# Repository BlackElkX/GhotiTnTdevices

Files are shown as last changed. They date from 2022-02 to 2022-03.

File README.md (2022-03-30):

# GhotiTnTdevices

Self build esp device to transform simple LED-strip designligts into wifi controlled dimable devices.

A very simple ui is available in browser.
A rest api is available.

- A schema and pcb layout is available, in the directory fritzing
- I use IR540 mosfets to drive the led strips. They stay very cool, because they are overrated for these strips.
- As source, the original 24V power suply is powerfull enough.
- I use as development and debug a NodeMCU ESP8266 module.
- As production boards, D1 mini is used.
- For the button array, I use 4x 10k ohm resistors, whish give on the NodeMCU
   - values 10, 550, 730, 815
   - a hysteresis of 42
   - and maxvalue of 980

  I did some tests, with other resistors, but 10k is the most stable.
   (dataExample/config.json is based on this tests)

  On D1 mini its more accurate, hyst is lower and values are different.

  To calibrate, use serial console, uncomment Serial.println line in main::readAnalogSensor(...
  - Serial.println("old = " + String(oldValue) + " new = " + String(newValue) + " max = " + String(maxValue) + " min = " + String(minValue));

Even Tasmota mentioned this board only suport up to 5 PWM channels, driving 6 PWM channels is not a problem.

V 0.0.7 - More scenes.
-------------------------------------

Todo:
- a switch to disable wifi functionality (only when power is off, you can use it. If powered, the switch will not be checked)
- a power switch (only on hardware level)
- an ap wifi mode with fixed ip address
- saving the config into the config.json file, from code.
- split up the values of the sensors and the outputs in different json files, in stead of the config.json file.
- a secure connection
- checking memory usage
- ...

Started:
- a decent web ui
- Digital buttons: support for same functions as in analog button array

Done:
- adding documentation about the rest api.
- 4 buttons using the A0 analog pin to use it stand-alone
- Solved bugs in programs not working. except scnone, scAllUpDown and scRandom
- platformio.ini: add default port

To build this, I use platformio in visual studio code on Mac, Linux and Windows.

Upload is as follow:
 1) in platformio.ini, select the correct board.
 2) edit the data/config.json file, to meet your desired configuration
    tip: set debug.enabled on true, for first attempt to use it.
         also, put your ssid and passphrase here before building the file system.
 3) in the platformio tab -> general -> Build to build it. (or below the screen, the V)
 4) in the platformio tab -> platform -> Build Filesystem Image
 5) in the platformio tab -> platform -> Upload Filesystem Image
 6) in the platformio tab -> general -> Upload. (or below the screen, the ->)
 
 you can check the serial monitor if it is working and to get the ip address.

 #Electronics
 In the folder fritzing, you can find the file with the schema.
 A PCB layout is also designed in this.

 #housing
 In 3D-models, an openScad file with a generated stl file is added.

 #Change log

 0.0.7: More Scenes
        - Added a demo scene, whish loops over all scenes.
        - Changed the order of the types: #None is the first in the list now.
        - Added scene table on HTML-page
        - Added default monitor port in platformio.ini

 0.0.6: Digital Buttons
        provided the same button functions for digital inputs as analog buttons.

 0.0.5: Analog Buttons
        Using the analog input with an array of buttons with a resistor network, up to 4 functions are usable:
        1 power on/off
        2 dimming up
        3 dimming down
        4 scene selection (loop over all scenes)

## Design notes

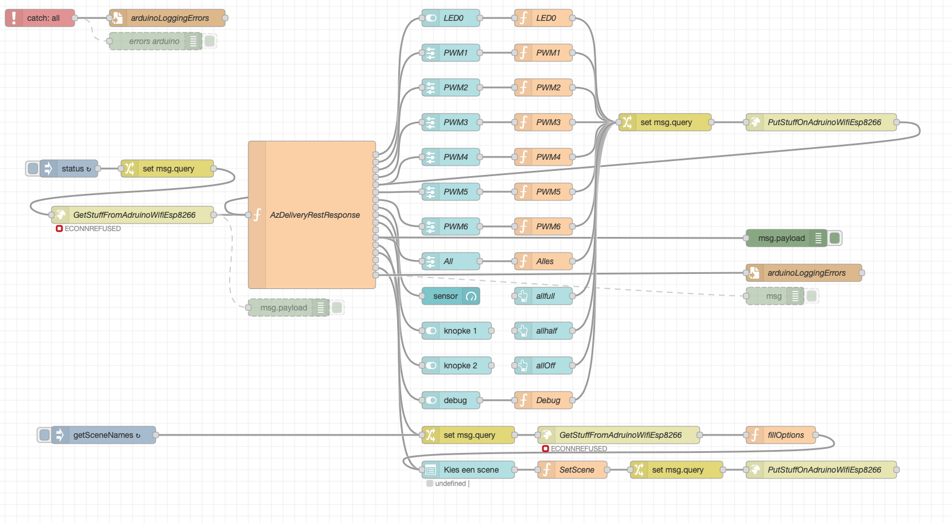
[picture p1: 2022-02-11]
documentation/noderedExample.png

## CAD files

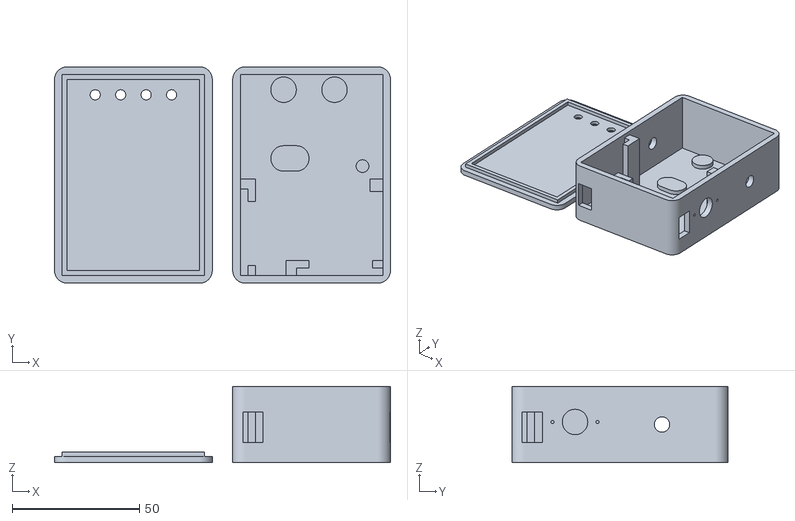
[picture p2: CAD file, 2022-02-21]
3D-models/stl/Box.stl
132.0 x 85.0 x 30.0

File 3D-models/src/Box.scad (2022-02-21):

$fn = 64;

test = false;

hoogte  = 30;
lengte  = 83;
breedte = 60;
dekselhoogte = 2.5;

if (test) {
  translate([24, 4, 2]) lolin();
  translate([3,  lengte - 43, 4]) mosfetpcb();
  translate([14, lengte - 69, 2]) dc2dc();
  translate([4, 36, 2]) rotate([0, 0, -90]) lolin();
  translate([0, 0, hoogte]) deksel();
}

difference() {
  roundedBox(5, 1.25, lengte, breedte, hoogte);
  binnenkant(hoogte, true);
  translate([breedte - 10, 3, 8]) cube([20, 8, 12]); //usb
  translate([3, -1.25, 8]) cube([8, 20, 12]); //usb 2
  translate([breedte - 6, 15, hoogte / 2]) rotate([90, 0, 90]) dcplug(0.65);
  translate([-6, lengte - 25, hoogte / 2]) rotate([90, 0, 90]) ledlampplug();
}

translate([-breedte - 10, lengte, dekselhoogte]) rotate([180, 0, 0]) deksel();

translate([breedte - 7, lengte - 48, 0]) cube([5, 5, hoogte - 2]);
lolinhouder();
translate([0, 60, 0]) rotate([0, 0, -90]) lolinhouder();


module deksel() {
  color("lime") {
    difference() {
      union() {
        roundedBox(5, 1.25, lengte, breedte, dekselhoogte);
        translate ([0, 0, -dekselhoogte*1.5]) binnenkant(dekselhoogte, false);
      }
      translate([5, 10, -1]) knoppen(4);
    }
  }
  //translate([5, 10, -1]) knoppen(4);
}

module lolinhouder() {
  translate([20, 1, 1])
    difference() {
      cube([39, 7, hoogte - 3]);
      translate([9, 1, 0]) cube([25, 7, 7]);
      translate([9, 1, 6]) cube([35, 7, 30]);
      translate([4, 1, 0]) cube([35, 3, 30]);
    }
}

module binnenkant(hoogte, tekenBodem) {
  difference() {
    translate([2, 2, 2]) cube([56, lengte - 4, hoogte]);
    if (tekenBodem) {
      bodem();
    } else {
      translate([4, 4, -1]) cube([52, lengte - 8, hoogte * 4]);
    }
  }
}

module bodem() {
  translate([19, lengte - 8, 0]) cylinder(r = 5, h = 4);
  translate([39, lengte - 8, 0]) cylinder(r = 5, h = 4);
  hull() {
    translate([19, lengte -35, 0]) cylinder(r = 5, h = 4);
    translate([24, lengte - 35, 0]) cylinder(r = 5, h = 4);
  }
  translate([50, lengte - 38, 0]) cylinder(r = 2.5, h = 4);
}

module lolin() {
  color("blue") cube([34, 1, 25]);
  color("grey") translate([27, 1, 8]) cube([7, 3, 8]);
  color("lime") translate([15, 0, 0]) cube([12, 5, 3]);
}

module mosfetpcb() {
  color("cyan") cube([53, 40, 2]);
}

module dc2dc() {
  color("darkblue") cube([43, 21, 2]);
}

module dcplug(schroefrad) {
  translate([17.68 / 2, 1, 1]) cylinder(r =          5, h = 10);
  translate([        0, 1, 1]) cylinder(r = schroefrad, h = 10);
  translate([17.68    , 1, 1]) cylinder(r = schroefrad, h = 10);
}

module ledlampplug() {
  cylinder(r = 3, h = breedte + 20);
}

module knoppen(aantal) {
  for (index = [1 : aantal]) {
    translate([10 * index, 0, 0]) cylinder(d = 4, h = dekselhoogte+1.25);
    translate([10 * index, 0, dekselhoogte]) cylinder(d = 6, h = dekselhoogte);
  }
/*  translate([20, 0, 0]) cylinder(d = 4, h = 20);
  translate([30, 0, 0]) cylinder(d = 4, h = 20);
  translate([40, 0, 0]) cylinder(d = 4, h = 20);*/
}

module roundedBox(radius, shift, length, width, height) {
  hull() {
    translate([radius / shift,                  radius / shift, 0]) cylinder(r = radius, h = height);
    translate([radius / shift,         length - radius / shift, 0]) cylinder(r = radius, h = height);
    translate([width - radius / shift, length - radius / shift, 0]) cylinder(r = radius, h = height);
    translate([width - radius / shift,          radius / shift, 0]) cylinder(r = radius, h = height);
  }
}

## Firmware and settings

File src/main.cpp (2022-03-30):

#include "Types.hpp"
#include "ProcessRequest.hpp"
#include "HtmlPage.hpp"
#include "Global.hpp"
#include "Scenes.hpp"
#include "PersistentSettings.hpp"
#include "Types.hpp"
#include <ArduinoJson.h>
#include <Server.h>
#include <ESP8266WiFi.h>
#include <ESP8266WebServer.h>
#include <ESP8266mDNS.h>

#define  VERSION_STRING "0.0.7"

extern DebugStruct debugInfo;
extern HtmlStruct  htmlInfo;
extern SceneStruct sceneInfo;
extern WifiStruct  wifiInfo;

extern int outputQuantity;
extern OutputStruct outputInfo[USED_OUTPUT_QTY];
extern int sensorQuantity;
extern SensorStruct sensorInfo[USED_SENSOR_QTY];

WiFiServer       httpSrv(80); //webserver
ESP8266WebServer restSrv(81); //restserver
unsigned long timestamp;

void initiateValues() {
  if (debugInfo.pin > -1) {
    pinMode(debugInfo.pin, INPUT);
  }
  for (int index = 0; index < outputQuantity; index++) {
    pinMode(outputInfo[index].pin, OUTPUT);
    digitalWrite(outputInfo[index].pin, outputInfo[index].value);
    debugLineToSerial("output " + String(index) + " (" + outputInfo[index].name + ") is set: pin " + String(outputInfo[index].pin) + " (" + outputInfo[index].pinName + ") = " + String(outputInfo[index].value));
  }
  for (int index = 0; index < sensorQuantity; index++) {
    pinMode(sensorInfo[index].pin, INPUT);
    debugLineToSerial("sensor " + String(index) + " (" + sensorInfo[index].name + ") is set: pin " + String(sensorInfo[index].pin) + " (" + sensorInfo[index].pinName + ") = " + String(sensorInfo[index].value));
  }
}

void setupSerialDebug() {
  Serial.begin(115200);
  Serial.println("");
  Serial.println("Version " + String(VERSION_STRING));
}

void setupWiFi() {
  Serial.println("");
  Serial.println("");
  Serial.println("");
  Serial.print("Connecting to the Newtork");
  WiFi.mode(WIFI_STA);
  WiFi.begin(wifiInfo.nameSSID, wifiInfo.passphrase);

  while (WiFi.status() != WL_CONNECTED) {
    delay(500);
    Serial.print(".");
  }

  Serial.println("");
  Serial.print("WiFi connected to ");
  Serial.println(wifiInfo.nameSSID);
  Serial.print("IP Address of network: ");
  Serial.println(WiFi.localIP());
}

// Manage not found URL
void handleNotFound() {
  String message = "File Not Found\n\n";
  message += "URI: ";
  message += restSrv.uri();
  message += "\nMethod: ";
  message += (restSrv.method() == HTTP_GET) ? "GET" : "POST";
  message += "\nArguments: ";
  message += restSrv.args();
  message += "\n";
  for (uint8_t i = 0; i < restSrv.args(); i++) {
    message += " " + restSrv.argName(i) + ": " + restSrv.arg(i) + "\n";
  }
  restSrv.send(404, "text/plain", message);
}

void setDebuging() {
  debugToSerial("set debugging to: ");
  debugToSerial(restSrv.argName(0));
  debugToSerial(restSrv.arg(0));
  String response = "{\"setDebug\":\"";
  if (restSrv.arg(0) == "ON") {
    setDebug(true);
    response += "ON";
  } else if (restSrv.arg(0) == "OFF") {
    setDebug(false);
    response += "OFF";
  } else {
    response += "\", \"error\":\"" + restSrv.arg(0);
  }
  response += "\"}";
  debugLineToSerial(" => " + response);
  restSrv.send(200, "text/json", response);
}

String processOutput(String obj, String value) {
  String result = "";
  for (int index = 0; index < outputQuantity; index++) {
    if (obj.equals(outputInfo[index].name)) {
      String request = "/" + obj + "=" + value;
      debugLineToSerial(request);
      String lValue = "ON";
      switch (outputInfo[index].type) {
        case oLED:
          setOutputValue(index, processLED(request, outputInfo[index].name, outputInfo[index].value, outputInfo[index].pin));
          if (outputInfo[index].value == 0) {
            lValue = "OFF";
          }
          result = "{\"name\":\"" + outputInfo[index].name + "\", \"value\":\"" + lValue + "\"}";
          break;
        case oPWM:
          analogWrite(outputInfo[index].pin, value.toInt());
          setOutputValue(index, value.toInt());
          result = "{\"name\":\"" + outputInfo[index].name + "\", \"value\":\"" + String(outputInfo[index].value) + "\"}";
          break;
        default:
          result = "{\"name\":\"" + outputInfo[index].name + "\", \"value\":\"type unknown\"}";
          break;
      }
    }
  }
  return result;
}

void getSceneNames() {
  debugToSerial("getting scene names");
  String response = "{\"scenes\":[";
  int index = 0;
  for (sceneTypes scene = scNone; scene <= scProgSequence; scene = sceneTypes(scene + 1)) {
    if (index > 0) {
      response += ", ";
    }
    index++;
    response += "\"" + getSceneTypeName(scene) + "\"";
  }
  response += "], \"default\":\"" + getSceneTypeName(scNone) + "\"}";
  
  debugLineToSerial(" => " + response);
  
  restSrv.send(200, "text/json", response);
}

void stopSceneNow() {
  if (sceneInfo.active != scNone) {
    stopScene();
    sceneInfo.active = scNone;
  }
}

void setOutput() {
  debugToSerial("setting output to: ");
  stopSceneNow();
  String response = "{\"outputs\":[";

  int argCount = restSrv.args();
  for (int index = 0; index < argCount - 1; index++) {
    debugToSerial(restSrv.argName(index) + " => " + restSrv.arg(index));
    String result = processOutput(restSrv.argName(index), restSrv.arg(index));
    if (index > 0) {
      response += ", ";
      debugToSerial(" - ");
    }
    response += result;
  }

  response += "]}";
  debugLineToSerial(" => " + response);
  restSrv.send(200, "text/json", response);
}

void setAllOffBtn() {
  stopSceneNow();
  for (int index = 0; index < outputQuantity; index++) {
    switch (outputInfo[index].type) {
      case oLED:
        digitalWrite(outputInfo[index].pin, LOW);
        setOutputValue(index, LOW);
        break;
      case oPWM:
        analogWrite(outputInfo[index].pin, 0);
        setOutputValue(index, 0);
        break;
      default:
        break;
    }
  }
}

void setAllOff() {
  debugToSerial("set all off: ");
  stopSceneNow();
  String response = "{\"outputs\":[";

  for (int index = 0; index < outputQuantity; index++) {
    debugToSerial(outputInfo[index].name + " => " + outputInfo[index].value);
    String lValue = "0";
    if (outputInfo[index].type == oLED) {
      lValue = "OFF";
    }
    String result = processOutput(outputInfo[index].name, lValue);
    if (index > 0) {
      response += ", ";
      debugToSerial(" - ");
    }
    response += result;
  }

  response += "]}";
  debugLineToSerial(" => " + response);
  restSrv.send(200, "text/json", response);
}

void setAllHalfBtn() {
  for (int index = 0; index < outputQuantity; index++) {
    if (outputInfo[index].type == oPWM) {
      analogWrite(outputInfo[index].pin, 127);
      setOutputValue(index, 127);
    }
  }
}

void setAllHalf() {
  debugToSerial("set all half:");
  stopSceneNow();
  String response = "{\"outputs\":[";

  int count = 0;
  for (int index = 0; index < outputQuantity; index++) {
    if (outputInfo[index].type == oPWM) {
      debugToSerial(outputInfo[index].name + " => " + outputInfo[index].value);
      String result = processOutput(outputInfo[index].name, "127");
      if (count > 0) {
        response += ", ";
        debugToSerial(" - ");
      }
      count++;
      response += result;
    }
  }
    
  response += "]}";
  debugLineToSerial(" => " + response);
  restSrv.send(200, "text/json", response);
}

void setAllFull() {
  debugToSerial("set all full:");
  stopSceneNow();
  String response = "{\"outputs\":[";

  for (int index = 0; index < outputQuantity; index++) {
    debugLineToSerial(outputInfo[index].name + " => " + outputInfo[index].value);
    String lValue = "255";
    if (outputInfo[index].type == oLED) {
      lValue = "ON";
    }
    String result = processOutput(outputInfo[index].name, lValue);
    if (index > 0) {
      response += ", ";
      debugToSerial(" - ");
    }
    response += result;
  }

  response += "]}";
  debugLineToSerial(" => " + response);
  restSrv.send(200, "text/json", response);
}

void setAllValueBtn(int amount) {
  for (int index = 0; index < outputQuantity; index++) {
    if (outputInfo[index].type == oPWM) {
      int newValue = outputInfo[index].value + amount;
      if (newValue < 0) {
        newValue = 0;
      }
      if (newValue > 255) {
        newValue = 255;
      }
      analogWrite(outputInfo[index].pin, newValue);
      setOutputValue(index, newValue);
    }
  }
}

bool checkAllOutputsOn() {
  bool result = false;
  for (int index = 0; index < outputQuantity; index++) {
    if (outputInfo[index].value > 0) {
      result = true;
    }
  }
  return result;
}

void setAllValue() {
  debugToSerial("set all:");
  stopSceneNow();
  String response = "{\"outputs\":[";

  int argCount = restSrv.args();
  debugLineToSerial(argCount);
  String aValue = restSrv.arg(0);
  int count = 0;
  for (int index = 0; index < outputQuantity; index++) {
    debugLineToSerial(outputInfo[index].name + " => " + outputInfo[index].value);
    String lValue = aValue;
    if (outputInfo[index].type == oLED) {
      if (aValue == "0") {
        lValue = "OFF";
      } else {
        lValue = "ON";
      }
    }
    String result = processOutput(outputInfo[index].name, lValue);
    if (count > 0) {
      response += ", ";
      debugToSerial(" - ");
    }
    count++;
    response += result;
  }
  response += "]}";
  debugLineToSerial(" => " + response);
  restSrv.send(200, "text/json", response);
}

void setNewScene() {
  debugToSerial("set scene to: ");
  String response = "{\"extra\":[";
  int argCount = restSrv.args();
  String sceneName;
  for (int index = 0; index < argCount; index++) {
    if (restSrv.argName(index) == "name") {
      sceneName = restSrv.arg(index);
    } else if (restSrv.argName(index) == "steps") {
      sceneInfo.steps_ms = restSrv.arg(index).toInt();
    } else if (restSrv.argName(index) == "pause") {
      sceneInfo.pause_ms = restSrv.arg(index).toInt();
    }
  }

  debugToSerial(sceneName);
  sceneTypes newscene = getSceneTypeFromName(sceneName);
  if (sceneInfo.active != newscene) {
    stopSceneNow();
    debugToSerial(" - selected scene = " + getSceneTypeName(newscene));
    sceneInfo.active = newscene;
    startScene();
  }

  response += "{\"name\":\"scene\", \"value\":\"";
  response += getSceneTypeName(sceneInfo.active);
  response += "\"}";
  response += ", {\"name\":\"steps\", \"value\":\"";
  response += String(sceneInfo.steps_ms);
  response += "\"}";
  response += ", {\"name\":\"pause\", \"value\":\"";
  response += String(sceneInfo.pause_ms);
  response += "\"}";
  response += "]}";
  debugLineToSerial(" => " + response);
  restSrv.send(200, "text/json", response);
}

void setStepsScene() {
  debugToSerial("set scene steps to: ");
  String response = "{\"extra\":[";

  int argCount = restSrv.args();
  debugLineToSerial(argCount);
  String sceneName;
  for (int index = 0; index < argCount; index++) {
    if (restSrv.argName(index) == "steps") {
      sceneInfo.steps_ms = restSrv.arg(index).toInt();
    } else {
      response += "\"error\":\"wrong rest call: " + restSrv.argName(index) + " is not valid for setSceneSteps\"";
    }
  }
  debugToSerial(sceneName);

  sceneTypes newscene = getSceneTypeFromName(sceneName);
  if (sceneInfo.active != newscene) {
    stopSceneNow();
    debugToSerial(" - selected scene = " + getSceneTypeName(newscene));
    sceneInfo.active = newscene;
    startScene();
  }

  response += "{\"name\":\"scene\", \"value\":\"";
  response += getSceneTypeName(sceneInfo.active);
  response += "\"}";
  response += ", {\"name\":\"steps\", \"value\":\"";
  response += String(sceneInfo.steps_ms);
  response += "\"}";
  response += ", {\"name\":\"pause\", \"value\":\"";
  response += String(sceneInfo.pause_ms);
  response += "\"}";
  response += "]}";
  debugLineToSerial(" => " + response);
  restSrv.send(200, "text/json", response);

}

void setPauseScene() {
  debugToSerial("set scene pause to: ");
  String response = "{\"extra\":[";

  int argCount = restSrv.args();
  debugLineToSerial(argCount);
  String sceneName;
  for (int index = 0; index < argCount; index++) {
    if (restSrv.argName(index) == "name") {
      sceneName = restSrv.arg(index);
    } else if (restSrv.argName(index) == "steps") {
      sceneInfo.steps_ms = restSrv.arg(index).toInt();
    } else if (restSrv.argName(index) == "pause") {
      sceneInfo.pause_ms = restSrv.arg(index).toInt();
    }
  }
  debugToSerial(sceneName);
  sceneTypes newscene = getSceneTypeFromName(sceneName);
  if (sceneInfo.active != newscene) {
    stopSceneNow();
    debugToSerial(" - selected scene = " + getSceneTypeName(newscene));
    sceneInfo.active = newscene;
    startScene();
  }

  response += "{\"name\":\"scene\", \"value\":\"";
  response += getSceneTypeName(sceneInfo.active);
  response += "\"}";
  response += ", {\"name\":\"steps\", \"value\":\"";
  response += String(sceneInfo.steps_ms);
  response += "\"}";
  response += ", {\"name\":\"pause\", \"value\":\"";
  response += String(sceneInfo.pause_ms);
  response += "\"}";
  response += "]}";
  debugLineToSerial(" => " + response);
  restSrv.send(200, "text/json", response);
}

void startActionOfAnalogButton(int index, int btnIndex) {
  switch (sensorInfo[index].btnArray[btnIndex].types) {
    case bPower:
      if (checkAllOutputsOn()) {
        setAllOffBtn();
      } else {
        setAllHalfBtn();
      }
      break;
    case bUp:
      setAllValueBtn(sensorInfo[index].btnArrayIncrease);
      break;
    case bDown:
      setAllValueBtn(-sensorInfo[index].btnArrayDecrease);
      break;
    case bProgram:
      sceneInfo.active = getNextSceneType(sceneInfo.active);
      startScene();
      break;
    default:
      break;
  }
}

void startActionOfDigitalButton(int index) {
  switch (sensorInfo[index].digitalFunction) {
    case bPower:
      if (checkAllOutputsOn()) {
        setAllOffBtn();
      } else {
        setAllHalfBtn();
      }
      break;
    case bUp:
      setAllValueBtn(sensorInfo[index].btnArrayIncrease);
      break;
    case bDown:
      setAllValueBtn(-sensorInfo[index].btnArrayDecrease);
      break;
    case bProgram:
      sceneInfo.active = getNextSceneType(sceneInfo.active);
      startScene();
      break;
    default:
      break;
  }
}

void processAnalogButtonArray(int index) {
  for (int btnIndex = 0; btnIndex < 4; btnIndex++) {
    int low  = sensorInfo[index].btnArray[btnIndex].resitor - sensorInfo[index].hysteresis;
    int high = sensorInfo[index].btnArray[btnIndex].resitor + sensorInfo[index].hysteresis;
    if ((sensorInfo[index].value > low) && (sensorInfo[index].value < high)) {
      if (!sensorInfo[index].btnArray[btnIndex].pressed) {
        sensorInfo[index].btnArray[btnIndex].pressed = true;
        startActionOfAnalogButton(index, btnIndex);
      }
    } else {
      sensorInfo[index].btnArray[btnIndex].pressed = false;
    }
  }
}

String getAnalogButtonArrayDetails(int index) {
  String result = "";
  for (int btnIndex = 0; btnIndex < 4; btnIndex++) {
    if (btnIndex > 0) {
      result += ", ";
    }
    result += "{\"name\": \"" + sensorInfo[index].name + "-" + String(btnIndex + 1) + "\", \"value\":";
    if (sensorInfo[index].btnArray[btnIndex].pressed) {
      result += "\"ON\"";
    } else {
      result += "\"OFF\"";
    }
    result += ", \"type\": \"" + getButtonTypeName(sensorInfo[index].btnArray[btnIndex].types) + "\"}";
  }
  debugLineToSerial(" " + result);
  return result;
}

void getStatus() {
  debugToSerial("getting status from rest api: ");
  String response = "{";

  //outputs
  response += "\"outputs\":[";
  int  lLEDValue    = -1;
  bool LEDDifferent = false;
  int  lPWMValue    = -1;
  bool PWMDifferent = false;
  for (int index = 0; index < outputQuantity; index++) {
    if (index > 0) {
      response += ", ";
    }
    String lValue = "ON";
    switch (outputInfo[index].type) {
      case oLED:
        if (outputInfo[index].value == 0) {
          lValue = "OFF";
        }
        if (lLEDValue != outputInfo[index].value) {
          if (lLEDValue > -1) {
            LEDDifferent = true;
          }
          lLEDValue = outputInfo[index].value;
        }
        response += "{\"name\":\"" + outputInfo[index].name + "\", \"value\":\"" + lValue + "\", \"type\":\"" + getOutputTypeName(outputInfo[index].type) + "\"}";
        break;
      case oPWM:
        response += "{\"name\":\"" + outputInfo[index].name + "\", \"value\":\"" + String(outputInfo[index].value) + "\", \"type\":\"" + getOutputTypeName(outputInfo[index].type) + "\"}";
        if (lPWMValue != outputInfo[index].value) {
          if (lPWMValue > -1) {
            PWMDifferent = true;
          }
          lPWMValue = outputInfo[index].value;
        }
        break;
      default:
        response += "{\"name\":\"" + outputInfo[index].name + "\", \"value\":\"n/a\",\"type\":\"type unknown\"}";
        break;
    }
  }
  response += "]";

  //sensors
  response += ", \"sensors\":[";
  for (int index = 0; index < sensorQuantity; index++) {
    if (index > 0) {
      response += ", ";
    }
    String lValue = "ON";
    switch (sensorInfo[index].type) {
      case sDigital:
        if (sensorInfo[index].value == 0) {
          lValue = "OFF";
        }
        response += "{\"name\":\"" + sensorInfo[index].name + "\", \"value\":\"" + lValue + "\", \"type\":\"" + getSensorTypeName(sensorInfo[index].type) + "\"}";
        break;
      case sAnalog:
        response += "{\"name\":\"" + sensorInfo[index].name + "\", \"value\":\"" + String(sensorInfo[index].value) + "\", \"type\":\"" + getSensorTypeName(sensorInfo[index].type) + "\"}";
        break;
      case sAnalogButtons:
        response += "{\"name\":\"" + sensorInfo[index].name + "\", \"value\":\"" + String(sensorInfo[index].value) + "\", \"type\":\"" + getSensorTypeName(sensorInfo[index].type) + "\", \"buttons\":[";
        response += getAnalogButtonArrayDetails(index);
        response += "]}";
        break;
      default:
        response += "{\"name\":\"" + sensorInfo[index].name + "\", \"value\":\"type unknown\"}";
        break;
    }    
  }
  response += "]";

  //gezamelijk
  response += ", \"generals\":[";

  if (!LEDDifferent) {
    String lValue = "ON";
    if (lLEDValue == 0) {
      lValue = "OFF";
    }
    response += "{\"name\":\"LEDS\", \"value\":\"" + lValue + "\"}";
  }
  if (!LEDDifferent && !PWMDifferent) {
    response += ", ";
  }
  if (!PWMDifferent) {
    response += "{\"name\":\"PWMS\", \"value\":\"" + String(lPWMValue) + "\"}";
  }
  response += "]";

  //extras, like scene, debug status, ...
  response += ", \"extra\":[{\"name\":\"scene\", \"value\":\"";
  response += getSceneTypeName(sceneInfo.active);
  response += "\"}";
  response += ", {\"name\":\"steps\", \"value\":\"";
  response += String(sceneInfo.active);
  response += "\"}";
  response += ", {\"name\":\"pause\", \"value\":\"";
  response += String(sceneInfo.active);
  response += "\"}";
  response += ", {\"name\":\"debug\", \"value\":\"";
  if (getDebug()) {
    response += "ON";
  } else {
    response += "OFF";
  }
  response += "\"}, {\"name\":\"debugPin\", \"value\":\"";
  if (getDebugPinState()) {
    response += "ON";
  } else {
    response += "OFF";
  }
  response += "\"}";
  response += "]}";

  debugLineToSerial(response);

  restSrv.send(200, "text/json", response);
}

// Define routing
void restServerRouting() {
  restSrv.on("/", HTTP_GET, []() {
    restSrv.send(200, F("text/html"),
    F("Welcome to the REST Web Server"));
  });
  restSrv.on(F("/status"),        HTTP_GET, getStatus);
  restSrv.on(F("/getSceneNames"), HTTP_GET, getSceneNames);
  restSrv.on(F("/setOutput"),     HTTP_PUT, setOutput);
  restSrv.on(F("/setDebug"),      HTTP_PUT, setDebuging);
  restSrv.on(F("/setAllOff"),     HTTP_PUT, setAllOff);
  restSrv.on(F("/setAllHalf"),    HTTP_PUT, setAllHalf);
  restSrv.on(F("/setAllFull"),    HTTP_PUT, setAllFull);
  restSrv.on(F("/setAllValue"),   HTTP_PUT, setAllValue);
  restSrv.on(F("/setScene"),      HTTP_PUT, setNewScene);
  restSrv.on(F("/setSceneSteps"), HTTP_PUT, setStepsScene);
  restSrv.on(F("/setScenePause"), HTTP_PUT, setPauseScene);
}

void setupRestSrv() {
  // Activate mDNS this is used to be able to connect to the server
  // with local DNS hostmane esp8266.local
  if (MDNS.begin("esp8266")) {
    Serial.println("MDNS responder started");
  }
  restServerRouting();
  // Set not found response
  restSrv.onNotFound(handleNotFound);
  // Start rest server
  restSrv.begin(wifiInfo.restPort);
  Serial.print("REST Server started, use URL: ");
  Serial.print(WiFi.localIP());
  Serial.print(":");
  Serial.println(wifiInfo.restPort);
  Serial.println("/status to get the status of everything.");
}

void loopREST() {
  restSrv.handleClient();
}
/*  end rest server  */

/*  start regular html page server  */
void setupHtmlSrv() {
  httpSrv.begin(wifiInfo.httpPort);  // Starts the Server
  Serial.print("HTTP Server started on port ");
  Serial.println(wifiInfo.httpPort);
  Serial.print("Copy and paste the following URL: https://");
  Serial.print(WiFi.localIP());
  Serial.print(":");
  Serial.print(wifiInfo.httpPort);
  Serial.println("/");
}
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
void loop() {
  loopREST();
  loopScene();
  loopBOARDsensors();
  HtmlStruct httpData;
  httpData.client = httpSrv.available();
  if (httpData.client) {
    debugLineToSerial("Waiting for new client");
    while(!httpData.client.available()) {
      delay(1);
    }
    httpData.request = httpData.client.readStringUntil('\r');
    debugLineToSerial(httpData.request);
    httpData.client.flush();
    loopHTTPBoardOutputs(httpData.request);
    loopHTTPpage(httpData.client);
    loopHTTPDebug();
  }  
}

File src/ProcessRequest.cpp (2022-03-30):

#include <WString.h>
#include <Arduino.h>
#include "Global.hpp"
#include "Types.hpp"

int processLED(String request, String obj, int iValue, int iLed) {
  int aValue = iValue;
  if (request.indexOf("/" + obj + "=ON") != -1) {
    aValue = HIGH;
  } else if (request.indexOf("/" + obj + "=OFF") != -1) {
    aValue = LOW;
  }
  digitalWrite(iLed, aValue);
  return aValue;
}

int processHtmlPWM(String request, String obj, int aValue, int iPwm) {
  int iValue = aValue;
  if (request.indexOf("/" + obj + "=255") != -1) {
    iValue = 255;
  } else if (request.indexOf("/" + obj + "=127") != -1) {
    iValue = 127;
  } else if (request.indexOf("/" + obj + "=0") != -1) {
    iValue = 0;
  } else if (request.indexOf("/" + obj + "=") != -1) {
    String pwmDummy = request.substring(request.indexOf("/" + obj + "="));
    debugToSerial(": " + pwmDummy);
    iValue = pwmDummy.toInt();
  }
  analogWrite(iPwm, iValue);
  debugLineToSerial(iValue);
  return iValue;
}

int processRefresh(String request, int arefreshrate) {
  int result = arefreshrate;
  if (request.indexOf("/refresh=on") != -1) {
    result = 5;
  } else if (request.indexOf("/refresh=off") != -1) {
    result = 0;
  }
  return result;
}

sceneTypes processScene(String request) {
  sceneTypes sceneType = scNone;
  if (request.indexOf("GET /scene=") != -1) {
    String newScene1 = request.substring(request.indexOf("GET /scene=") + 11);
    String newScene2 = newScene1.substring(0, newScene1.indexOf(" "));
    sceneType = getSceneTypeFromName(newScene2);
  }
  return sceneType;
}

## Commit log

2022-02-11 First submit
    This compiles, but is not yet fully working
    [TnTBigLamp-1pcb.fzz]
2022-02-11 NodeRed example
    A nodered flow as an example
2022-02-19 analogButtonArray
    Next step in analog button array processing
2022-02-19 bug fix in analog button array
    [main.cpp]
2022-02-19 Debugging button array
    Some temporary code to fine-tune the button array.
2022-02-19 next step in button array
2022-02-20 Button array almost working
2022-02-20 Definitive version Button array
    The button array is up and running.
2022-02-21 Initial production version
    - Solved bugs in programs
    - clean-up of code
    [main.cpp]
2022-02-21 Added 3D design
    A 3D design for a box added.
    [Box.scad, Box.stl]
2022-02-21 next step: Digital buttons
    Adding support for digital buttons with same functions as the buttons created in the analog button array.
2022-03-30 scene changes
    - Added a demo scene, whish loops over all scenes.
    - Changed the order of the types: #None is the first in the list now.
    - Added scene table on HTML-page
    - Added default monitor port in platformio.ini
    - some bug fixing
    [ProcessRequest.cpp]
